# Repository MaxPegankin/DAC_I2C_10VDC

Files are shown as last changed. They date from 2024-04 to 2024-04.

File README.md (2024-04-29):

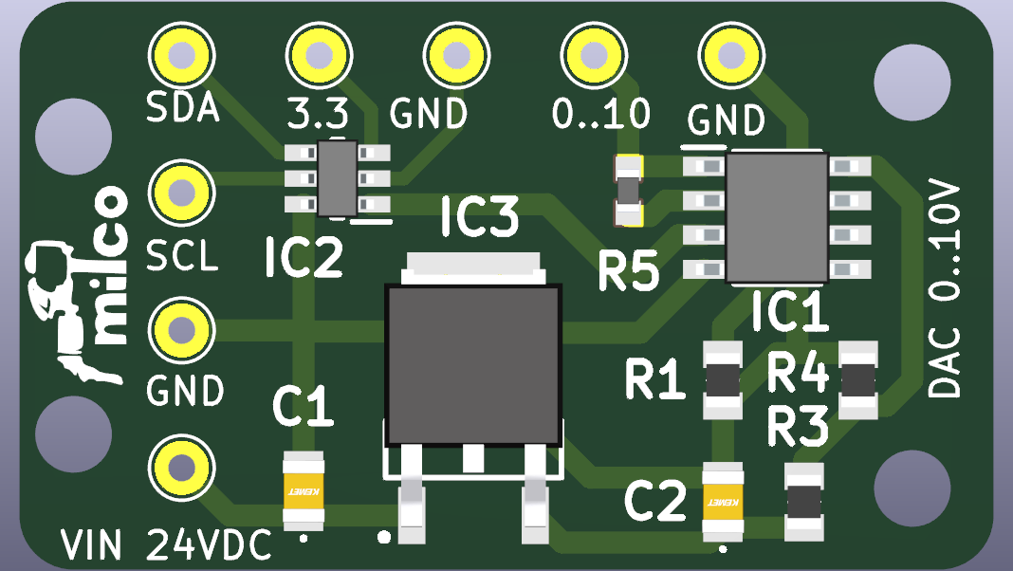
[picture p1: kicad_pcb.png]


# DAC_I2C_10VDC
I2C to MCP4725 to 0 . . 10VDC (from 24VDC) 

## Description
Digital Analog Converter</br>
Breakout board to convert I2C signal to 0 .. 10 VDC</br>
Designed with **Kicad 8** </br>
Mainly based on **MCP4725** </br>
3.3v or 5v power supply acceptable for I2C interface</br>
24VDC used for 0 .. 10VDC generation.</br>

Can be used with Arduino and Raspberry Pi boards.

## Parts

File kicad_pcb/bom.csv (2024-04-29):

Reference | Value | Datasheet | Footprint | Qty | DNP | Manufacturer_Part_Number | Mouser Part Number | Description
C1 | 0.33 uF 5% | https://content.kemet.com/datasheets/KEM_C1023_X7R_AUTO_SMD.pdf | Samacsys:C0805 | 1 |  | C0805C334J5RACAUTO | 80-C0805C334J5RAUTO | SMD Auto X7R, Ceramic, 0.33 uF, 5%, 50 VDC, 125 VDC, 125C, -55C, X7R, SMD, MLCC, Temperature Stable, Automotive Grade, 2.5 % , 1.5152 GOhms, 13 mg, 0805, 2mm, 1.25mm, 0.9mm, 0.75mm, 0.5mm, 4000, 78 Weeks, 80
C2 | 0.1 uF 5% | https://content.kemet.com/datasheets/KEM_C1075_X7R_HT_SMD.pdf | Samacsys:C0805 | 1 |  | C0805R104J5RACTU | 80-C0805R104J5RACTU | SMD Indust X7R HT175C, Ceramic, 0.1 uF, 5%, 50 VDC, 125 VDC, 175C, -55C, X7R, SMD, MLCC, High Temperature, FT-Cap, 2.5 % , 10 GOhms, 11 mg, 0805, 2mm, 1.25mm, 0.78mm, 0.75mm, 0.5mm, 4000, 78 Weeks, 80
IC1 | LM358DR2G | http://www.onsemi.com/pub/Collateral/LM358-D.PDF | Samacsys:SOIC127P600X175-8N | 1 |  | LM358DR2G | 863-LM358DR2G | LM358DR2G, Dual Operational Amplifier 5 to 28V, 8-Pin SOIC
IC2 | MCP4725A0T-E_CH | http://ww1.microchip.com/downloads/en/DeviceDoc/22039d.pdf | Samacsys:SOT95P270X145-6N | 1 |  | MCP4725A0T-E/CH | 579-MCP4725A0TECH | D/A Converter 12-Bit EEPROM I2C SOT23-6
IC3 | L78M24ACDT-TR | http://www.st.com/web/en/resource/technical/document/datasheet/CD00000447.pdf | Samacsys:TO228P972X240-3N | 1 |  | L78M24ACDT-TR | 511-L78M24ACDT-TR | L78M24ACDT-TR, Voltage Regulator, 0.5A 24 V, +/-2%, 3-Pin D-PAK
R1 | 10k 0.1% | https://componentsearchengine.com/Datasheets/1/TNPW080510K0BEEA.pdf | Samacsys:RESC2012X55N | 1 |  | TNPW080510K0BEEA | 71-TNPW080510K0BEEA | Thin Film Resistors - SMD 10Kohms .1% 25ppm
R3,R4 | 1.5k 0.1% |  | Samacsys:RESC2012X55N | 2 |  | TNPW08051K50BEEA | 71-TNPW08051K50BEEA | Thin Film Resistors - SMD 1.5Kohms .1% 25ppm
R5 | 20.3k 0.1% |  | Snapeda:RN73H1JTTD2032B25_RESC1608X55N | 1

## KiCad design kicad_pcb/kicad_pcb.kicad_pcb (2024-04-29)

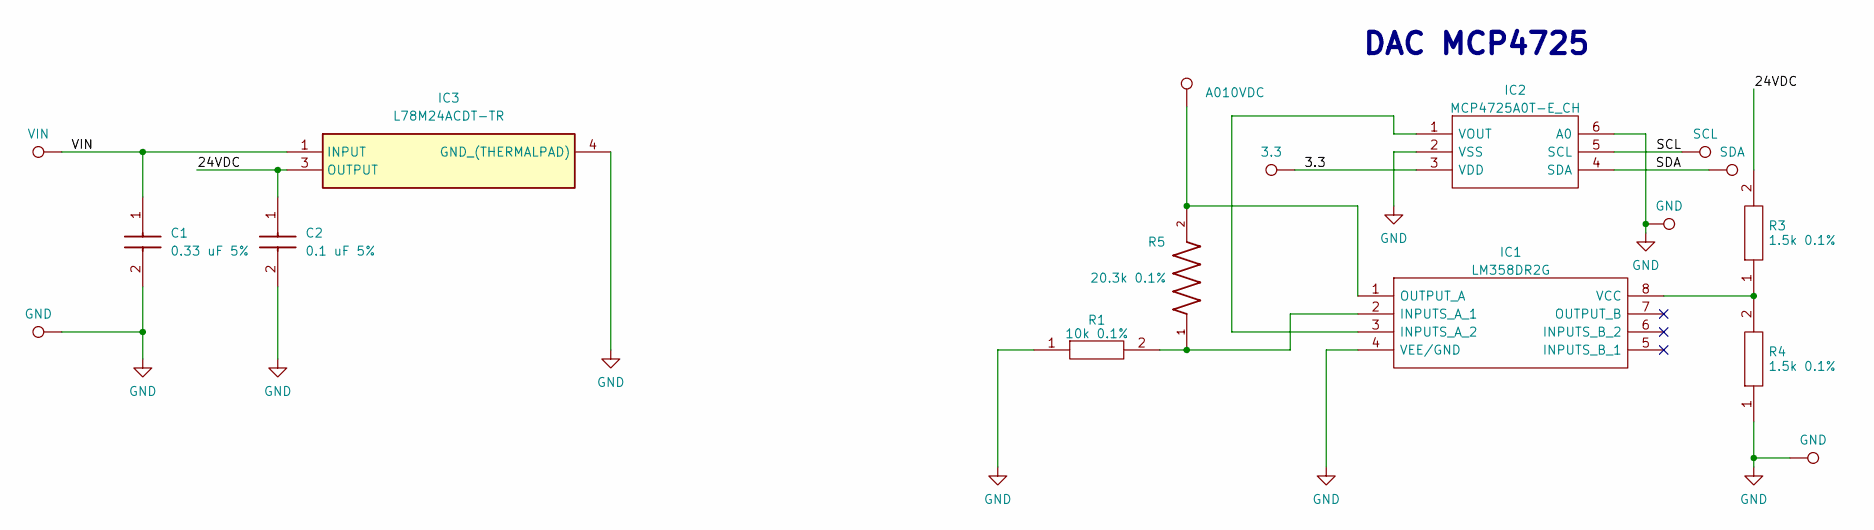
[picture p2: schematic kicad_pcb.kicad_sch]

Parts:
C1: 0.33 uF 5%; C0805; Mouser Part Number 80-C0805C334J5RAUTO
C2: 0.1 uF 5%; C0805; Mouser Part Number 80-C0805R104J5RACTU
IC1: LM358DR2G; SOIC127P600X175-8N; Mouser Part Number 863-LM358DR2G
IC2: MCP4725A0T-E_CH; SOT95P270X145-6N; Mouser Part Number 579-MCP4725A0TECH
IC3: L78M24ACDT-TR; TO228P972X240-3N; Mouser Part Number 511-L78M24ACDT-TR
R1: 10k 0.1%; RESC2012X55N; Mouser Part Number 71-TNPW080510K0BEEA
R3, R4: 1.5k 0.1%; RESC2012X55N; Mouser Part Number 71-TNPW08051K50BEEA
R5: 20.3k 0.1%; RN73H1JTTD2032B25_RESC1608X55N
TP1: VIN; TestPoint_THTPad_D2.0mm_Drill1.0mm
TP2: 3.3; TestPoint_THTPad_D2.0mm_Drill1.0mm
TP3: SCL; TestPoint_THTPad_D2.0mm_Drill1.0mm
TP4: SDA; TestPoint_THTPad_D2.0mm_Drill1.0mm
TP5, TP7, TP8: GND; TestPoint_THTPad_D2.0mm_Drill1.0mm
TP6: A010VDC; TestPoint_THTPad_D2.0mm_Drill1.0mm

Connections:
/3.3: IC2.3 (VDD), TP2.1
/24VDC: C2.1, IC3.3 (OUTPUT), R3.2
/SCL: IC2.5 (SCL), TP3.1
/SDA: IC2.4 (SDA), TP4.1
/VIN: C1.1, IC3.1 (INPUT), TP1.1
GND: C1.2, C2.2, IC1.4 (VEE/GND), IC2.2 (VSS), IC2.6 (A0), IC3.4 (GND_(THERMALPAD)), R1.1, R4.1, TP5.1, TP7.1, TP8.1
unnamed: IC1.2 (INPUTS_A_1), R1.2, R5.1
unnamed: IC1.3 (INPUTS_A_2), IC2.1 (VOUT)
unnamed: IC1.1 (OUTPUT_A), R5.2, TP6.1
unnamed: IC1.8 (VCC), R3.1, R4.2

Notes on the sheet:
DAC MCP4725

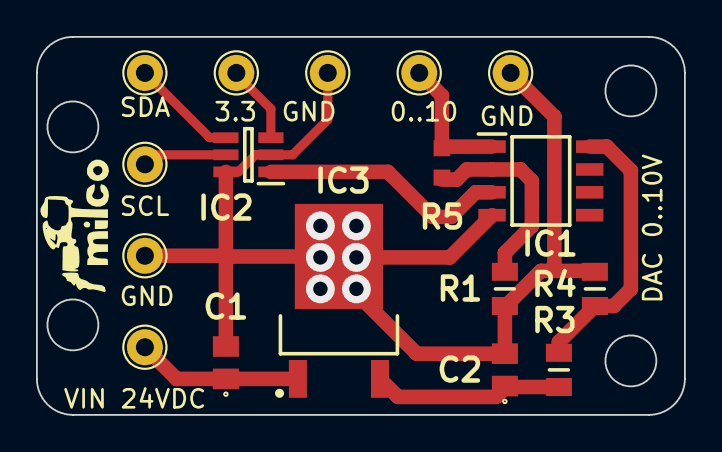
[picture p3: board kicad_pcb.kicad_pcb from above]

Board: 2 copper layers, 36.0 x 21.0 mm, 17 parts (0 on the bottom side), 10 nets.

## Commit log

2024-04-29 20.3k rsistor update
    [bom.csv, kicad_pcb.kicad_pcb, kicad_pcb.kicad_sch]
2024-04-29 20.3k resistor update to KOA
    [bom.csv, kicad_pcb.kicad_pcb, kicad_pcb.kicad_sch]
